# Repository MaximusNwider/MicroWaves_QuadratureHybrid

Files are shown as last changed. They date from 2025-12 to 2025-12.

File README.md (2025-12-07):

# Quadrature Hybrid Design Summary

<p align="justify">
This repository contains MATLAB tooling for comparing measured and simulated S-parameters of a quadrature hybrid. The pipeline ingests VNA Touchstone files alongside simulator exports, aligns the data to global S-parameter labels, and produces side-by-side comparison plots suitable for documentation and verification.
</p>

| Layout | Schematic |
| --- | --- |
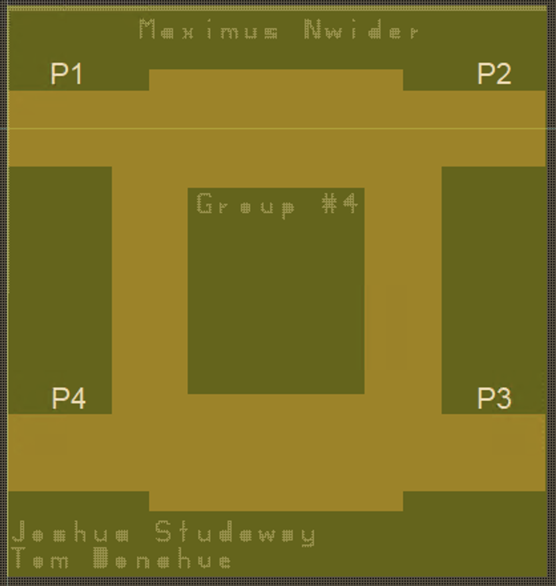
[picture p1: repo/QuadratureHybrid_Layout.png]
Quadrature Hybrid Layout
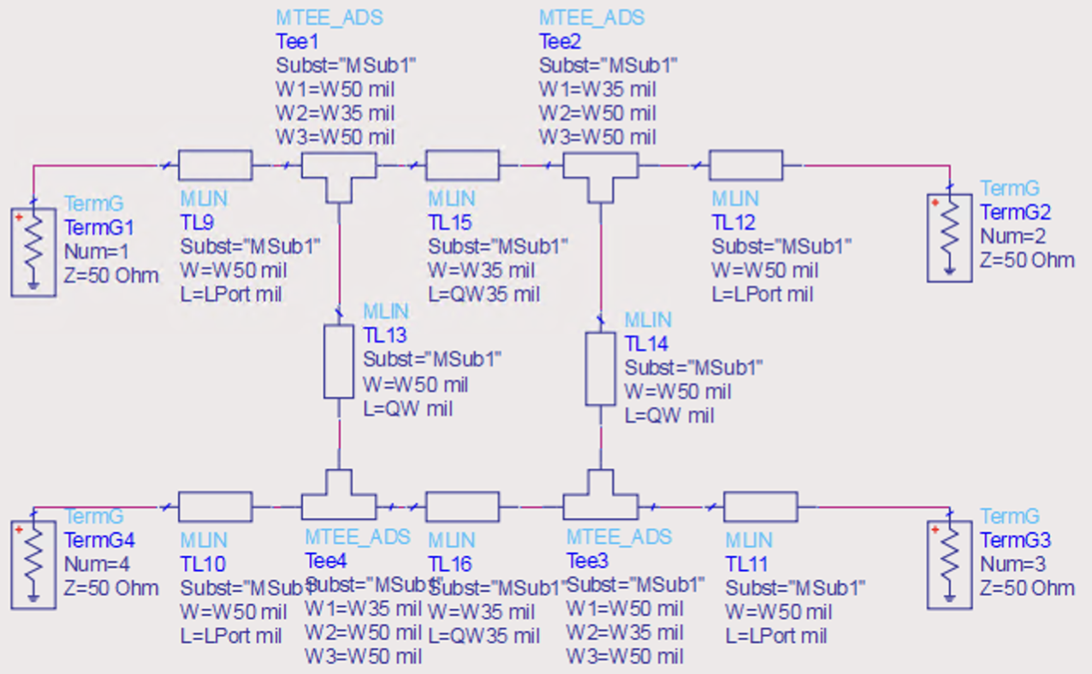
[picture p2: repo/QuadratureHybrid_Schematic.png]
Quadrature Hybrid Schematic
|  |  |

| ADS Simulation                                                          |
| ----------------------------------------------------------------------- |
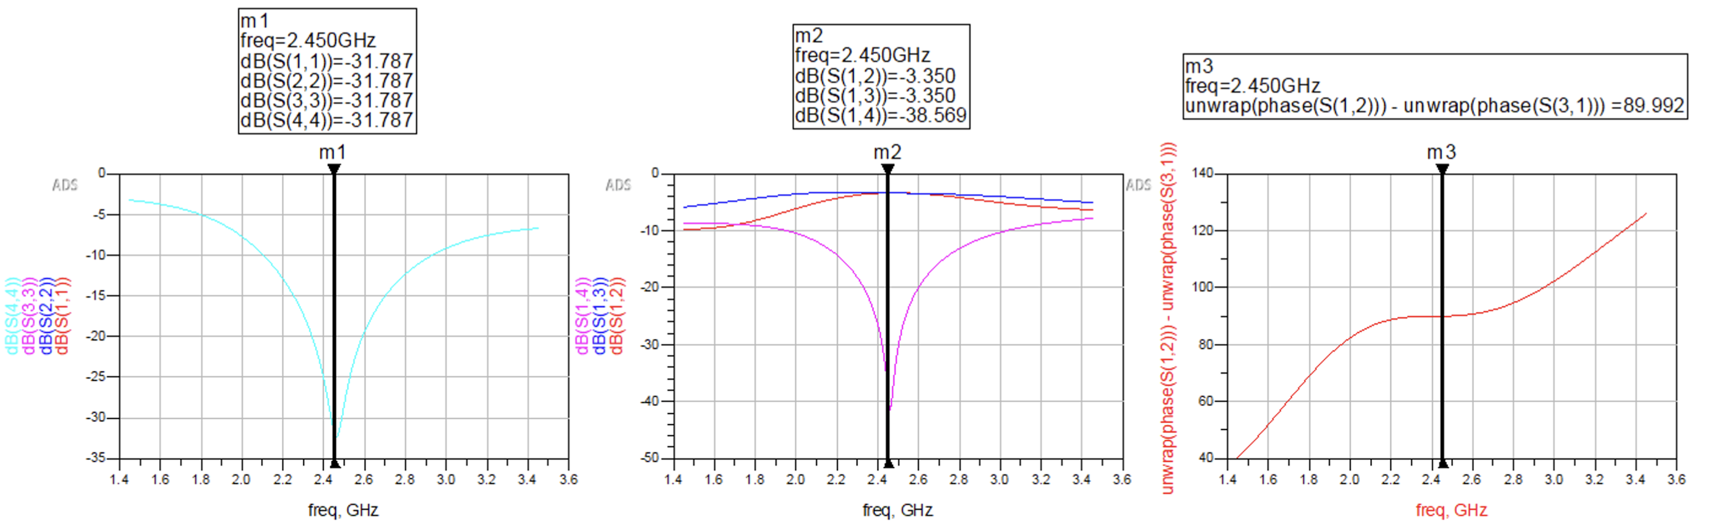
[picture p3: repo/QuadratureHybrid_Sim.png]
Quadrature Hybrid Simulation Overview
|  |

---

## Design Criteria

- **Center frequency:** 2.45 GHz
- **Return loss at all ports:** S11, S22, S33, S44 < -25 dB at 2.45 GHz
- **Power division:** S21 and S31 > -3.5 dB at 2.45 GHz
- **Isolation:** S41 < -30 dB at 2.45 GHz
- **Phase balance:** ∠S21 – ∠S31 = 90° at 2.45 GHz

---

## Substrate Properties

- **Substrate thickness (h):** 62 mil
- **Relative permittivity (εᵣ):** 4.4
- **Relative permeability (μᵣ):** 1
- **Conductor conductivity (σ):** 5.85 × 10⁷ S/m
- **Clearance to upper reference (hᵤ):** 3.93701 × 10³⁴ mil (effectively open)
- **Copper thickness (t):** 1.5 mil
- **Dielectric loss tangent (tan δ):** 0.02
- **Surface roughness:** 0 mil

---

## Repository Layout

- `main.m` — entry point that sets up paths, loads configuration, and launches the pipeline.
- `run_sparam_project.m` — orchestrates file discovery, measurement/simulation alignment, and plotting.
- `+config/` — default configuration values (paths, plotting options, axis limits).
- `+io/` — parsers for measurement (`*.s2p`) and simulation (`*.txt` / `*.tab` / `*.dat`) data.
- `+plotting/` — routines that generate comparison figures and save them to `output/`.
- `+util/` — helpers for path management and filename parsing.
- `+data/` — sample measurement and simulation files for local runs.
- `output/` — generated figures (`Sij.png`) for each available S-parameter.
- `repo/` — supporting figures
- `gerber/` — layout description, fabrication-ready.

---

## Running the Code

1. Open MATLAB and change into the repository folder.
2. Run the project entry point:

   ```matlab
   >> main
   ```

<p align="justify">
The script will read measurement and simulation files from the configured directories, map the local two-port VNA data to the appropriate global S-parameter labels, and write comparison plots into the <code>output/</code> directory for inspection and documentation.
</p>

---

## Measurement vs. Simulation

| S11 | S12 |
| --- | --- |
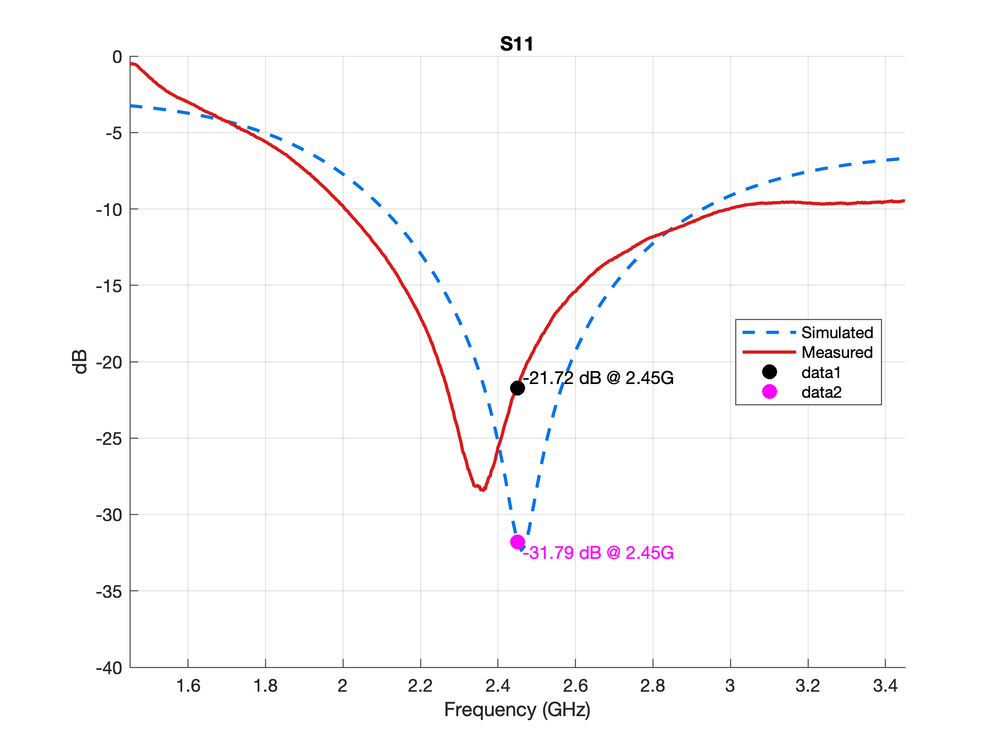
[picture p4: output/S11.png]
S11
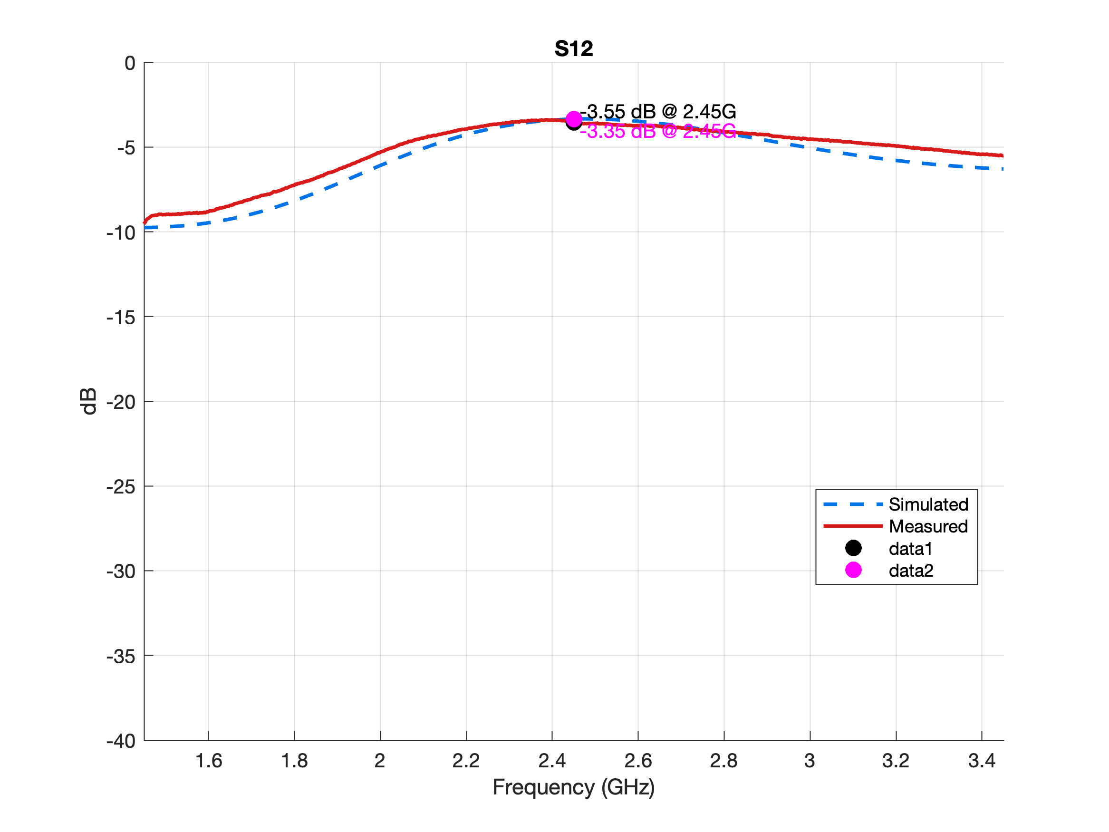
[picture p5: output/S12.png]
S12
|  |  |

| S13 | S14 |
| --- | --- |
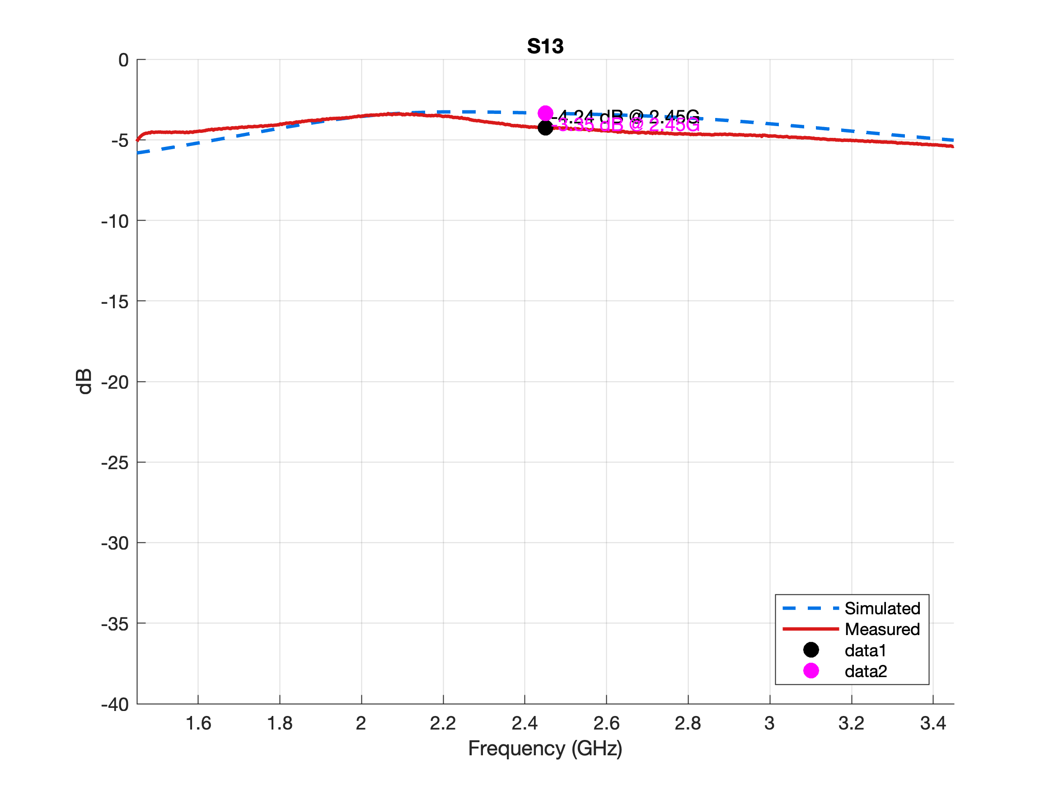
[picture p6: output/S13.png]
S13
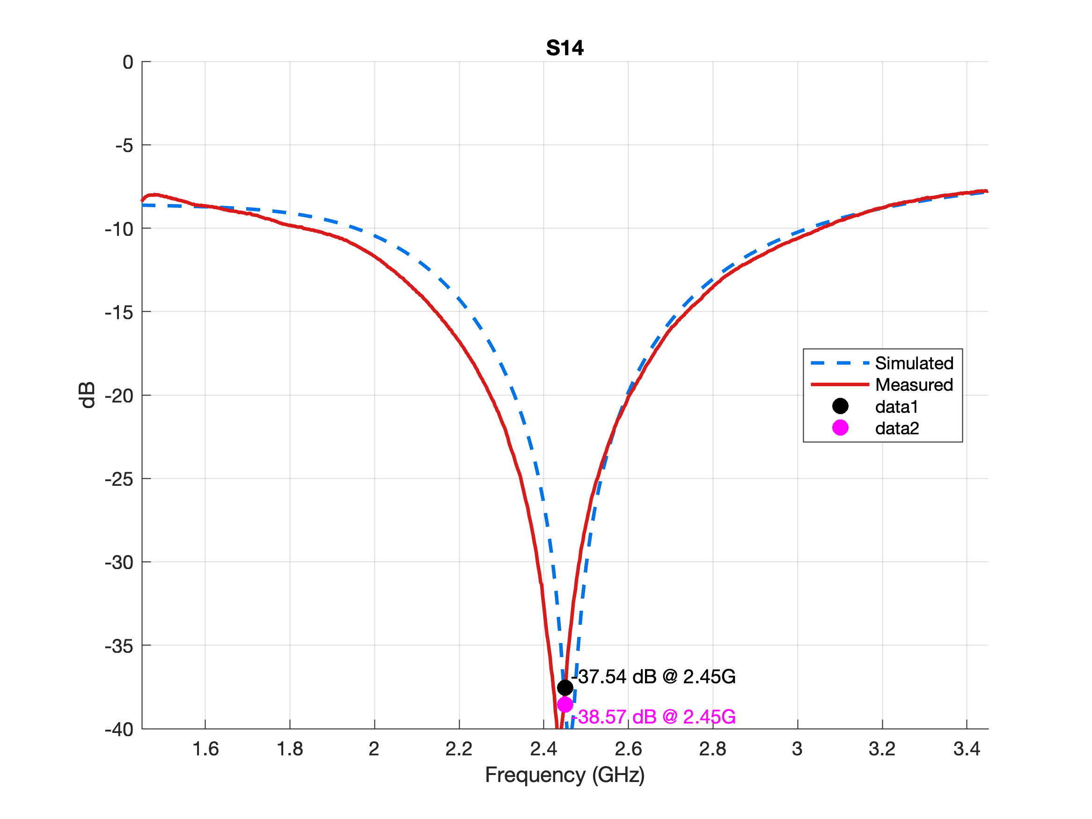
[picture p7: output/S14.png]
S14
|  |  |

| S21 | S22 |
| --- | --- |
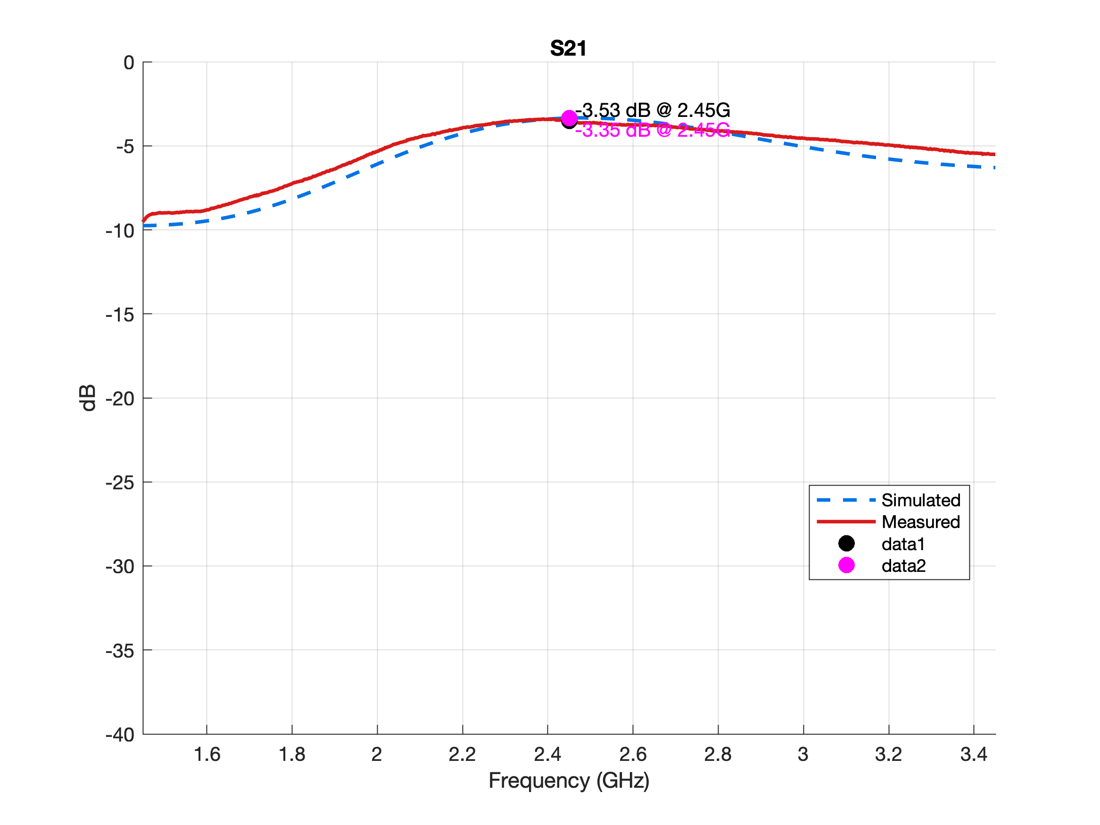
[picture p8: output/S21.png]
S21
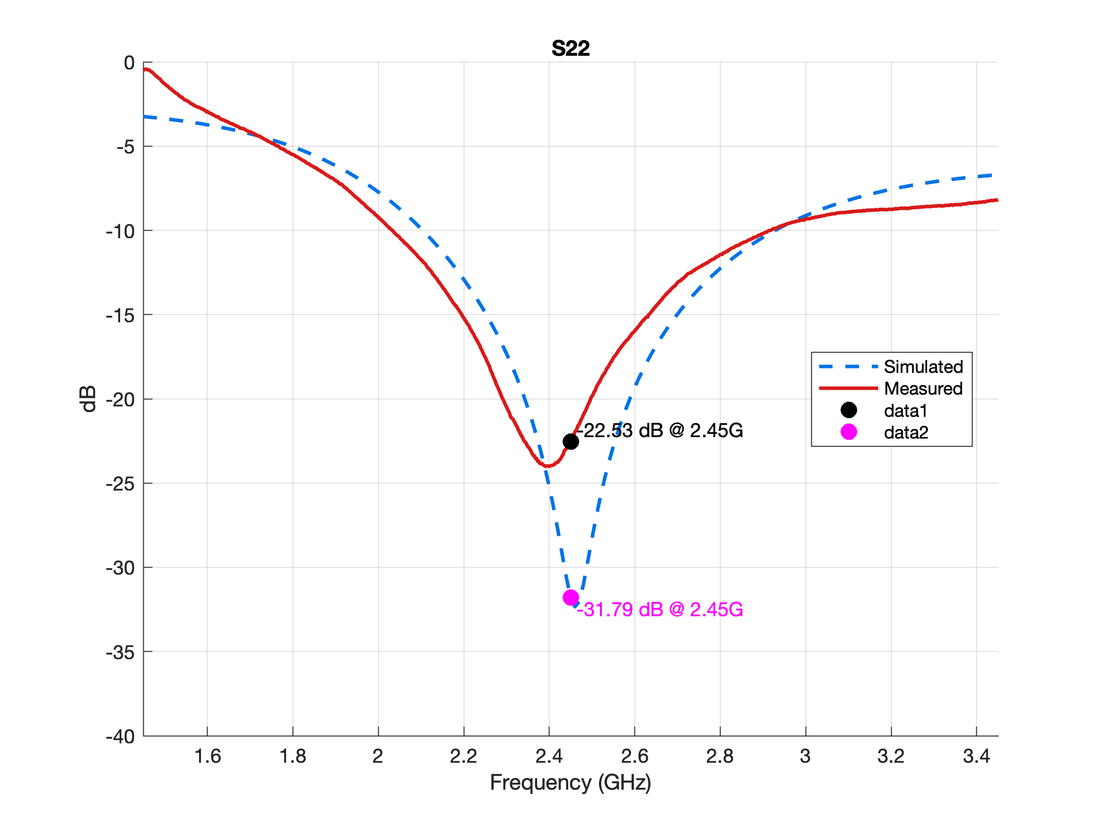
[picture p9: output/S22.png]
S22
|  |  |

| S23 | S31 |
| --- | --- |
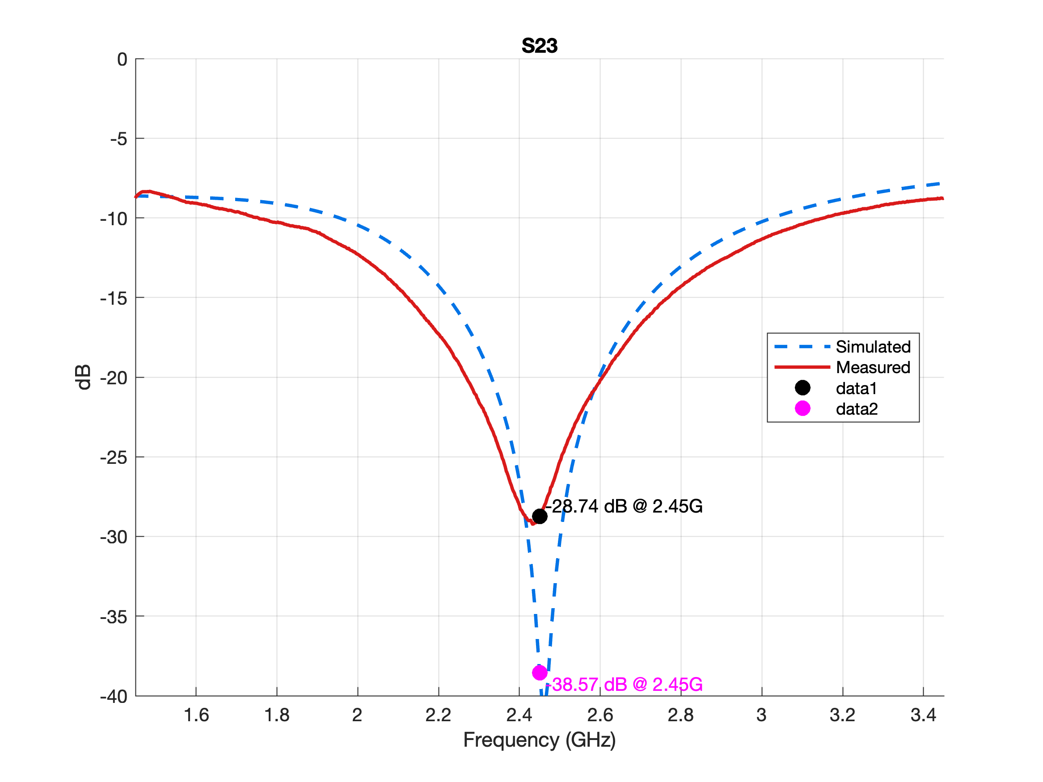
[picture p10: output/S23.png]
S23
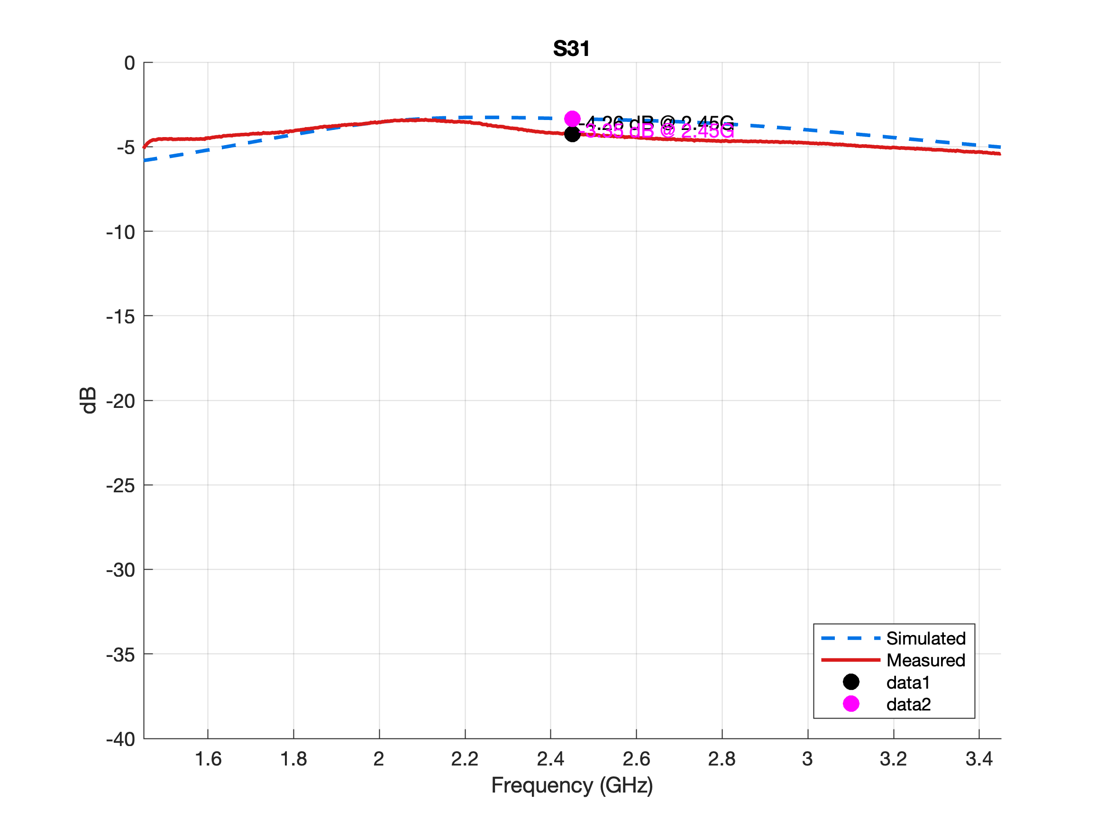
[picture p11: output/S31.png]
S31
|  |  |

| S32 | S33 |
| --- | --- |
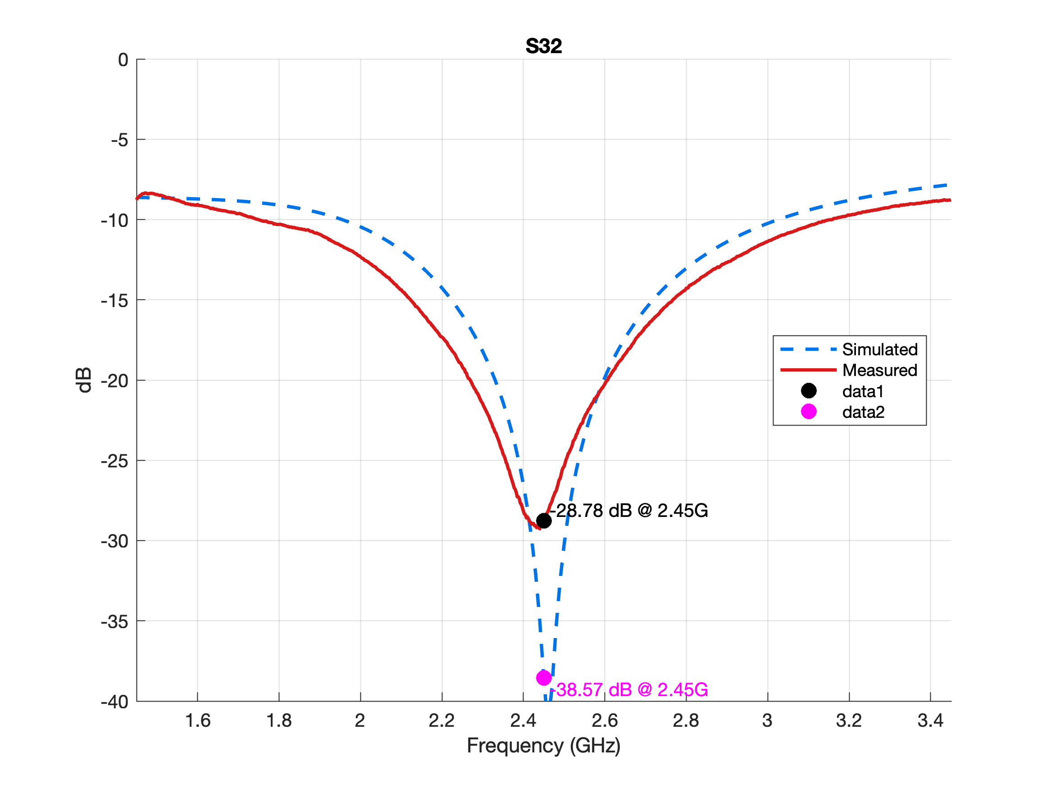
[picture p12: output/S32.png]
S32
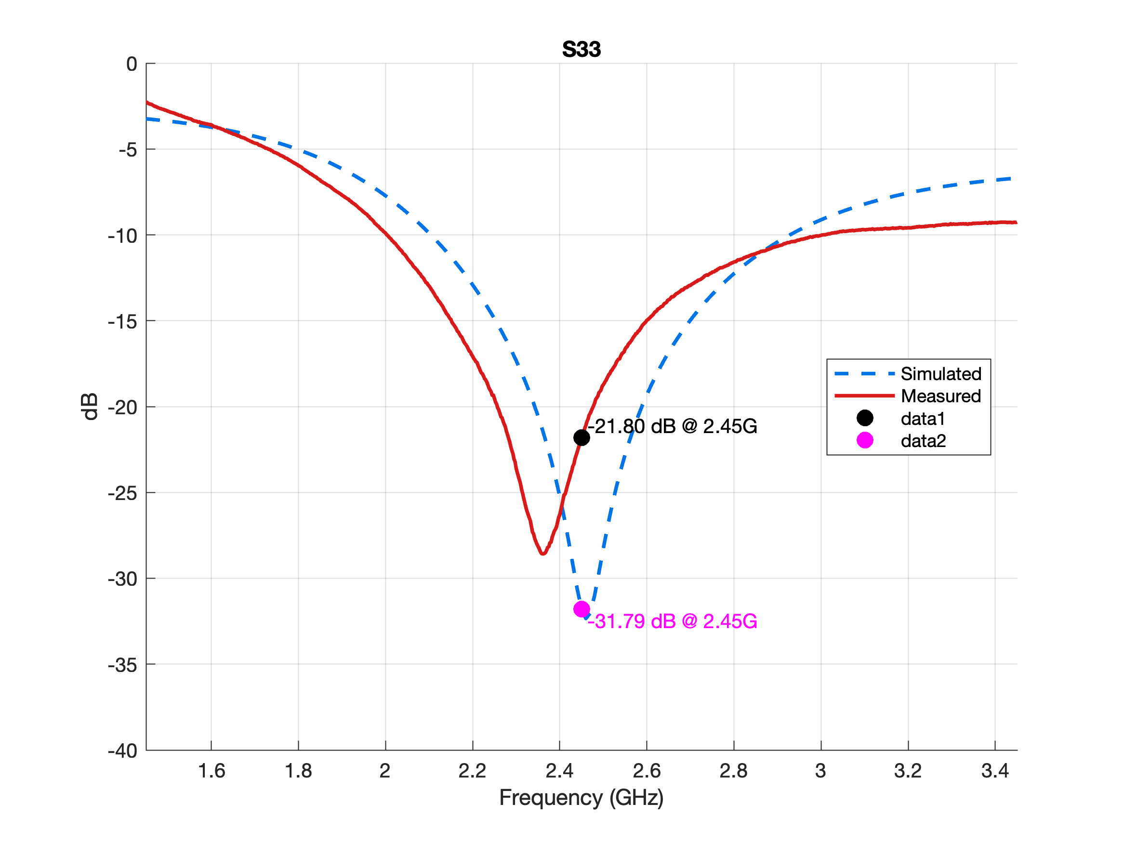
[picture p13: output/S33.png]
S33
|  |  |

| S41 | S44 |
| --- | --- |
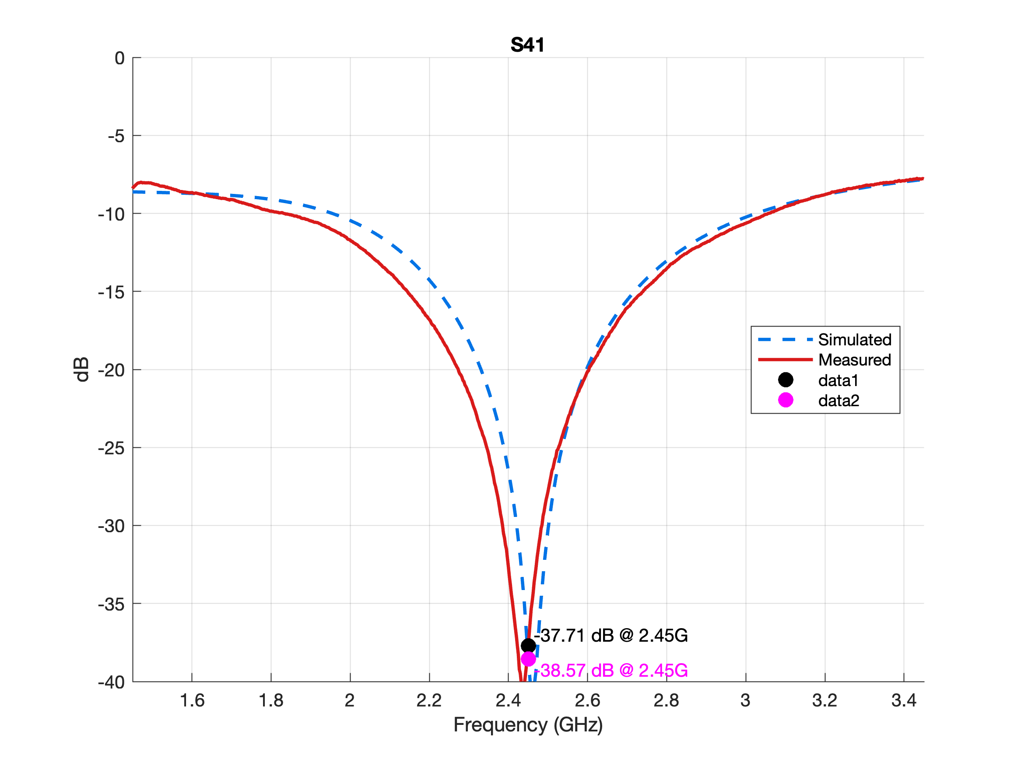
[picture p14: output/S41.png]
S41
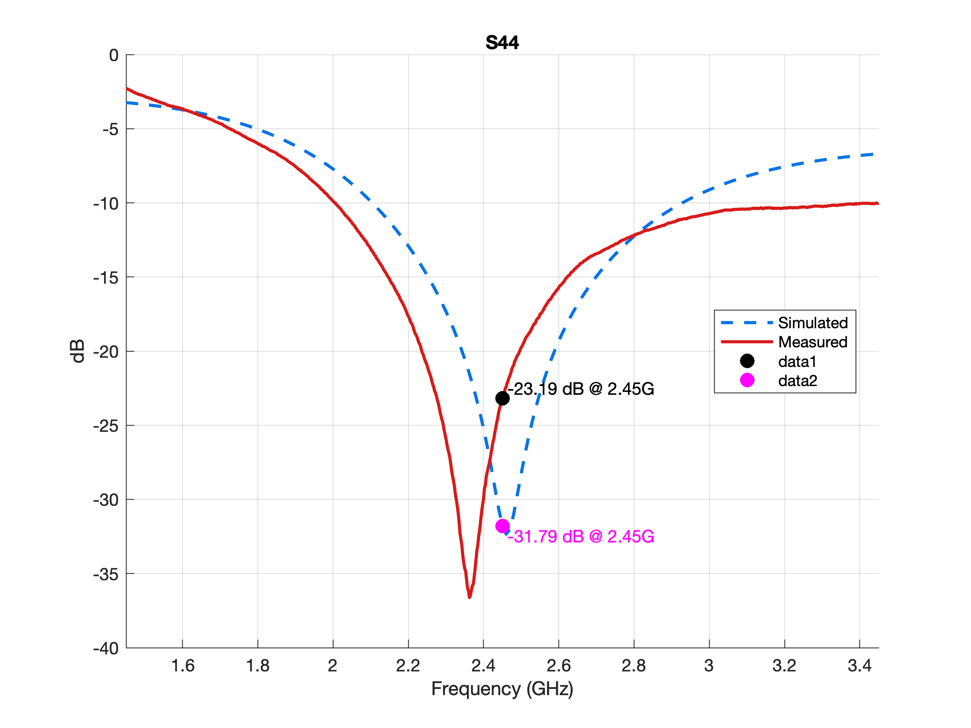
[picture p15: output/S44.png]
S44
|  |  |

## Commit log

2025-12-07 Original Quadrature Hybride @ 2.45GHz
    [dds.cfg, de_sim.cfg, hpeesofsim.cfg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]
2025-12-07 Gerber Layer Descriptions
    [cond.gbr, cond2.gbr, silk_screen.gbr]
2025-12-07 Entire ADS workspace
    [dds.cfg, de_sim.cfg, hpeesofsim.cfg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]
